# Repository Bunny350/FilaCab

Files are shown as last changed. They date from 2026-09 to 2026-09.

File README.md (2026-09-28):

# FilaCab

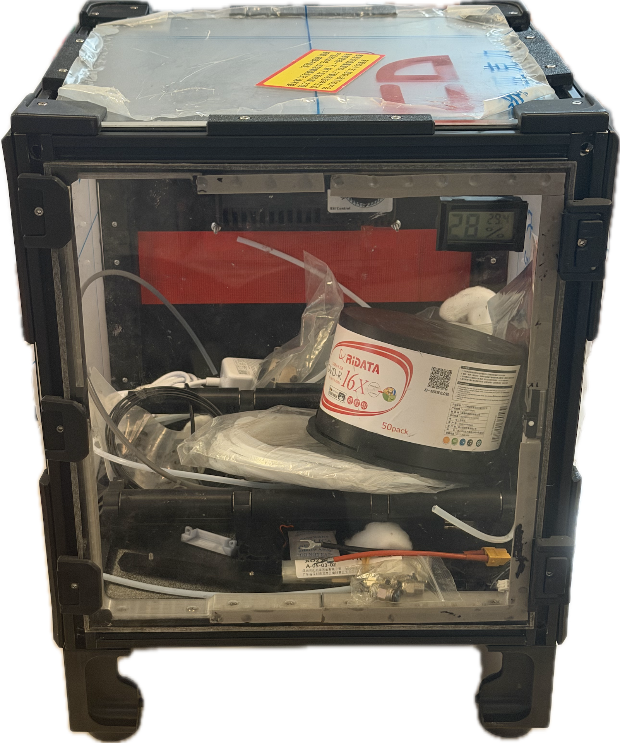
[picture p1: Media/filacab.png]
FilaCab


FilaCab is a 3-spool dry cabinet intended for storing FFF 3D printer filament spools with some Voron design. It contains parts derived from [V2, specifically my 150mm mod / OitswilliamV2](https://github.com/Bunny350/OitswilliamV2) and Voron Trident.

## Because there are no raw materials seen in the CAD, this lists (almost) all the raw materials.
* Side and back panel mounting brackets: 4X M3x10mm BHCS + 4X M3 T-wing or T-nuts per part, totaling 48X M3x10mm BHCS and 48X M3 T-wing or T-nuts,
* Top panel mounting brackets: 16X M3x8mm BHCS + 16X M3 T-wing or T-nuts,
* Panel shields (top and bottom): 4X M3x8mm SHCS + 4X M3 T-wing or T-nuts per part, totaling 32X M3x8mm SHCS and 32X M3 T-wing or T-nuts,
* Side shields (except back): 14X M3x6mm BHCS + 14X M3 T-wing or T-nuts and 2X M5x10mm BHCS + 2X M5 T-wing or T-nuts per side, totaling 38X M3x6mm, 38X M3 T-wing or T-nuts, 4X M5x10mm BHCS and 4X M5 T-wing or T-nuts,
* Back shield: 16X M3x6mm BHCS + 16X M3 T-wing or T-nuts,
* Front shield + frame-side door seal: 16X M3x8mm BHCS and 16X M3 T-wing or T-nuts,
* Dryer unit mounting: at least 4X M3x20mm BHCS + 4X M3 self-locking hex nuts,
* Filament holder with rollers (in case if it ever has MMU implemented): 12X F695 (ZZ or 2RS) bearings (inserted to the holders), 4X M5x10mm BHCS for mounting the roller to the bearings, 8X M3x12mm SHCS and 8X M3 T-wing or T-nuts
* Door seal magnets: Left 20X 6x3mm neodymium N35 magnets per side, Right 32X 6x3mm neodymium N35 magnets (the higher, the better), per side, totaling 104X of them.
  * Magnet placement guide: 
* File guides - CAD component
  * [ref] - reference material used for creating - do not print.
* File guides - printable parts
  * SIdes (after the part name), t - top, b - bottom, l - left, r - right. Some parts may use two-side combination i.e. tl\_br, meaning top-left, bottom-right.

## Development
The development began on 2023 with the first method being just heat, but the efficiency was too low with constant 200W, the second method replaces it with the Peltier, but it is also inefficient due to lacking of airflow. This is then changed to desiccant-based, which can drop to around 30%, or even around 20%.

This project has been released to the public because there are filament manufacturers began building filament dry cabinets, aside non-filament manufacturers have already been building these eons ago.

By using FilaCab, you agree to GNU GPLv3 which is available in the *LICENSE* document. FilaCab uses some parts from Voron 2, including the door hinge, some parts from Voron Trident, such as the feet, and [Snap Latch by richardjm](https://github.com/VoronDesign/VoronUsers/tree/main/printer_mods/richardjm/snap-latch-2020).

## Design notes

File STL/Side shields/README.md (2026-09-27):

# Side shields
This folder contains side shieldings for FilaCab, with the goal of reducing air leaks (as defined by unexpected humidity rise from outside factor).
## Left and right sides
They both use specific sets of `side_bracket_bl_X2.stl` and `side_bracket_br_X2.stl` while using a set of `side_bracket_tl_br_X4.stl` and `side_bracket_bl_tr_X4.stl`. They are mounted per side.
## Back side
This side uses two sets of `side_bracket_tl_br_X4.stl` and `side_bracket_bl_tr_X4.stl`, mounted on the back corners.

## File guide
Please refer to the root Readme file for the after-part name file guide.

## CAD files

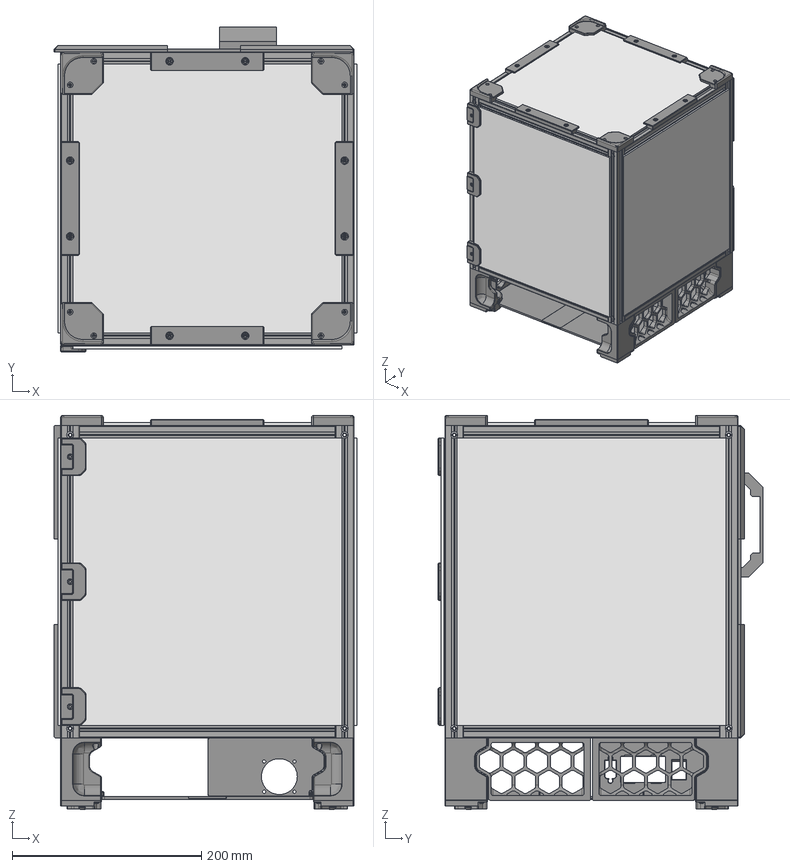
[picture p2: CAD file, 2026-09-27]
CAD/filacab.step
320.0 x 343.0 x 416.3 mm
M5x16 BHCS x 20
HFSB5-2020-430-LCP-RCP x 4
M3x6 BHCS (2)
M3x6 BHCS (19)
M3x6 BHCS (18)
M5x10 BHCS (32)
M3x8 SHCS (69)
M5x16 BHCS (5)
M5 Hex Nut (10)
M3x8 SHCS (70)
M5x10 BHCS (48)
M3x6 BHCS (22)
M3x6 BHCS (21)
M3x6 BHCS (20)
M5x16 BHCS (39)
M5 Hex Nut (12)
M3x8 SHCS (71)
M5x10 BHCS (5)
M3x6 BHCS (25)
M3x6 BHCS (24)
M3x6 BHCS (23)
M5x16 BHCS (40)
M5 Hex Nut (13)
M3x8 SHCS (72)
M5x10 BHCS (4)
M3x6 BHCS (28)
M3x6 BHCS (27)
M3x6 BHCS (26)
M5x16 BHCS (41)
M5 Hex Nut (14)
filament-spol-1kg
Panels
skirt assem
tooled roller
toolless roller
shaft
tooled roller(Mirror)
toolless roller(Mirror)
shaft(Mirror)
door_hinge_x6 (2)
M3x8 SHCS (122)
VHB (16)
M3 Hammerhead T-Nut (61)
door_hinge_x6
M3x8 SHCS (120)
VHB (19)
M3 Hammerhead T-Nut (59)
door_hinge_x6 (1)
M3x8 SHCS (121)
VHB (18)
M3 Hammerhead T-Nut (60)
reverse-stack
splitted bottom
panel mount
maglock
Bottom Panel
side extrusion cover
side extrusion cover(Mirror)
back extrusion cover
top corner extrusion cover

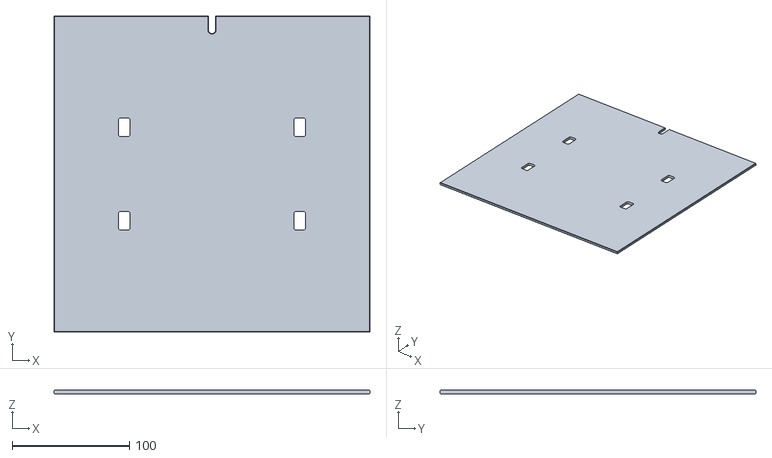
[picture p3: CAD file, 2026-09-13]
STL/bottom_panel_3mm.stl
270.0 x 270.0 x 3.00

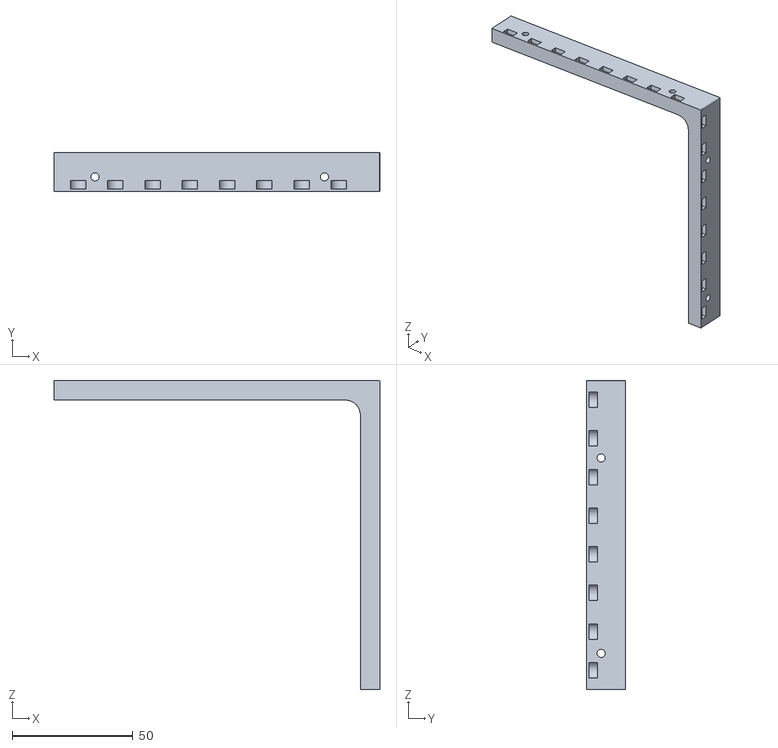
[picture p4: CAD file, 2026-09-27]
STL/Door seal - frame-side/seal_door_maglock_bl_tr_X2.stl
135.0 x 16.0 x 128.0

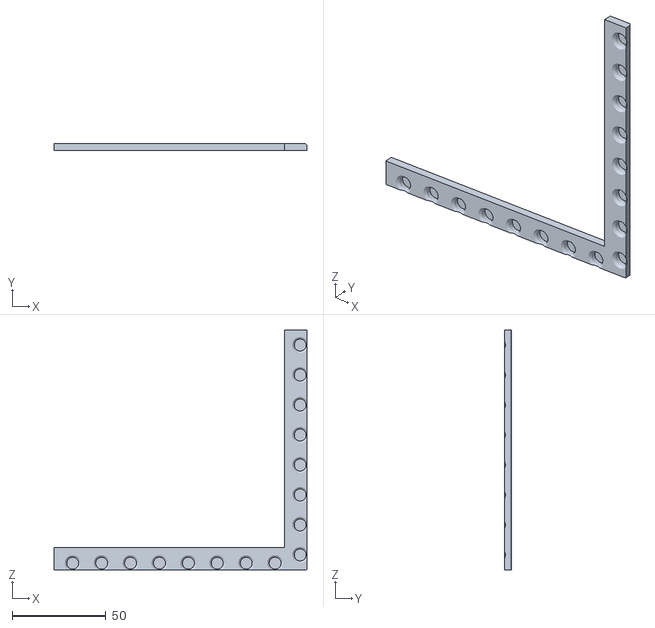
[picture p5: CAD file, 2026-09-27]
STL/Door seal - panel-side/panel_mag_l_tl_br_X2.stl
135.0 x 4.00 x 128.0

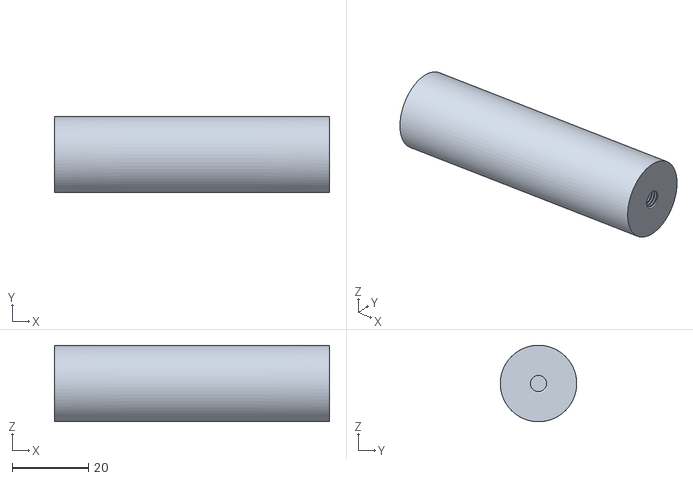
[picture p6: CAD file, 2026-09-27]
STL/Filament rolling/roller_m5_fasten_X4.stl
72.0 x 20.0 x 20.0

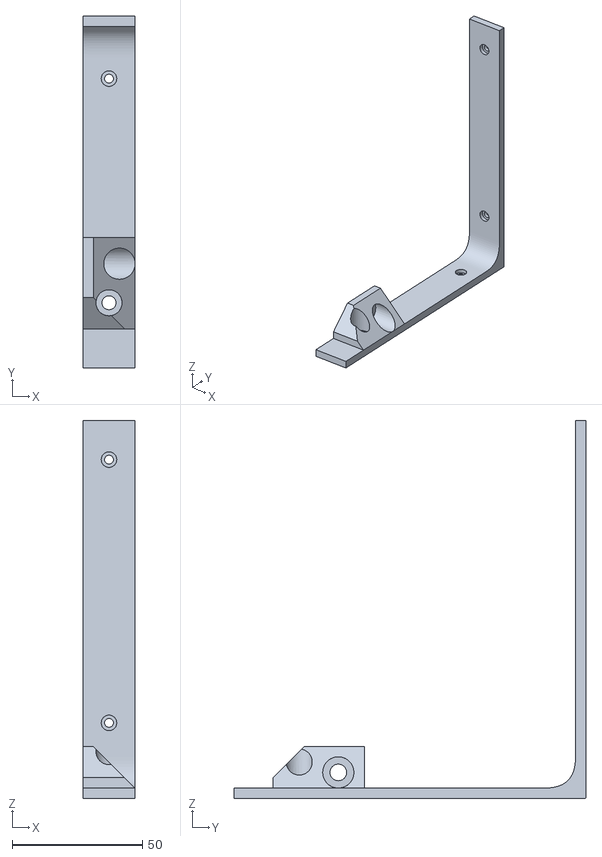
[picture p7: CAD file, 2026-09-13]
STL/Side shields/side_bracket_ext_br_X2.stl
20.0 x 135.0 x 145.0

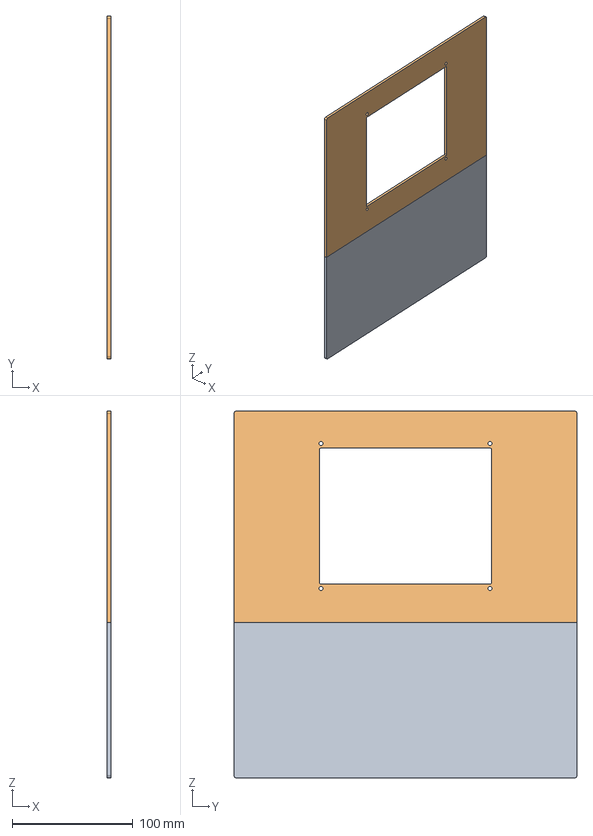
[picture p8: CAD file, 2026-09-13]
CAD/dehumidifier panel for last resort fila cab.step
3.00 x 284.0 x 304.0 mm

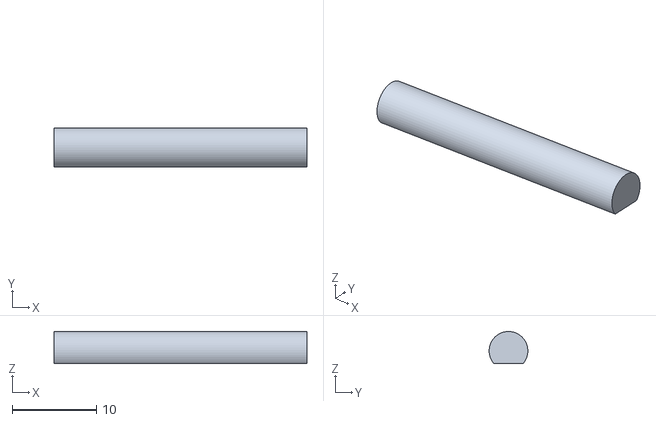
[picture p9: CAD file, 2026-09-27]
STL/Filament rolling/roller_toolless_shaft_X8.stl
30.0 x 4.59 x 3.80

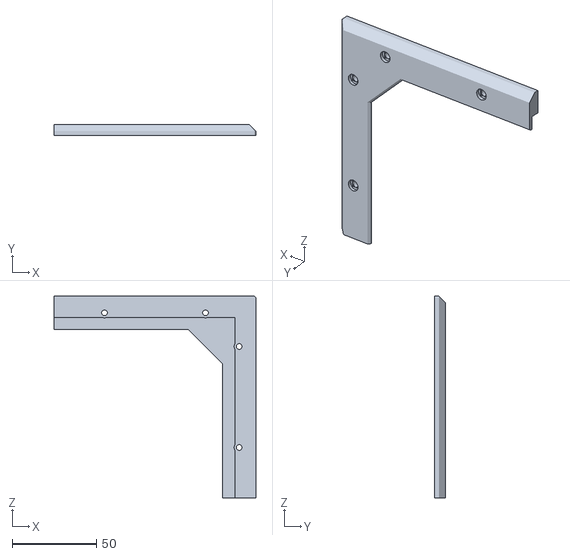
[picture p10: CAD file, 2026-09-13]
STL/panel_corner_mount_X12.stl
120.0 x 6.60 x 120.0

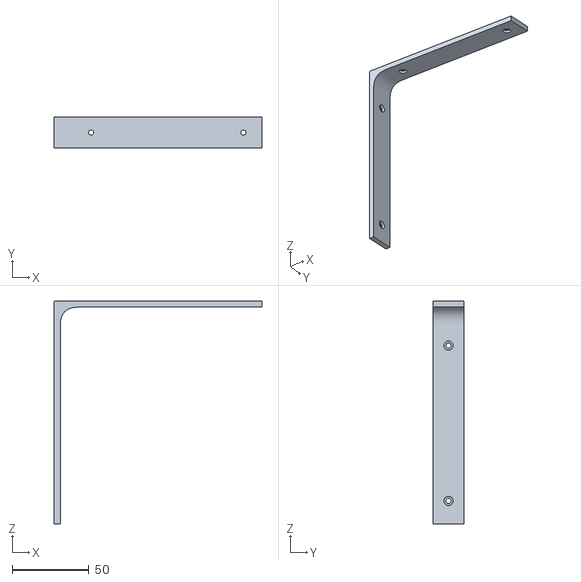
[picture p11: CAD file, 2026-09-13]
STL/Side shields/side_bracket_bl_tr_X4.stl
135.0 x 20.0 x 145.0

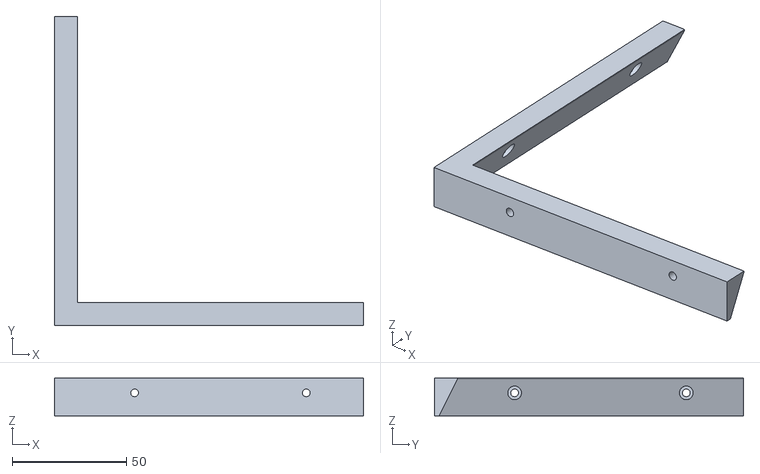
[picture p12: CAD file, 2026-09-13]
STL/bottom_panel_corner_X4.stl
135.0 x 135.0 x 16.4

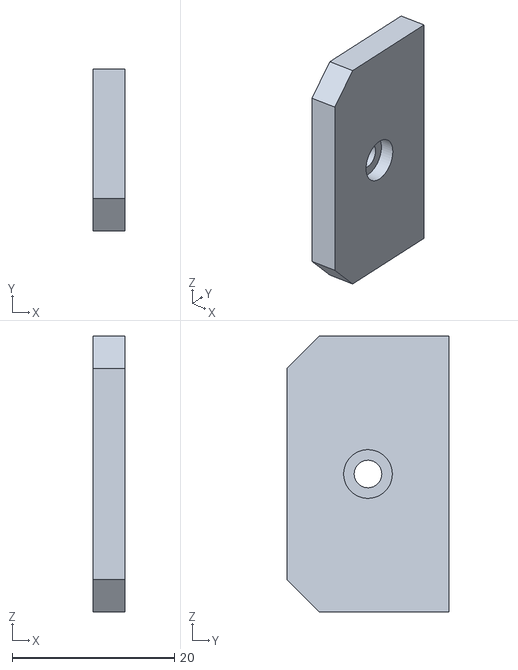
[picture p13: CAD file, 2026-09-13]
STL/Door seal - frame-side/panel_cover_l.stl
4.00 x 20.0 x 34.0

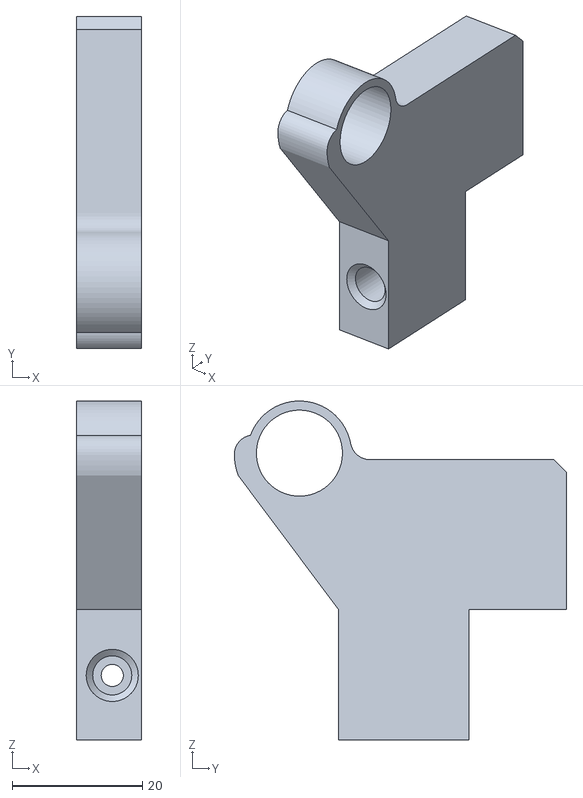
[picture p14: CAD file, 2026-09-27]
STL/Filament rolling/spool_holder_front_X4.stl
10.0 x 51.0 x 52.0

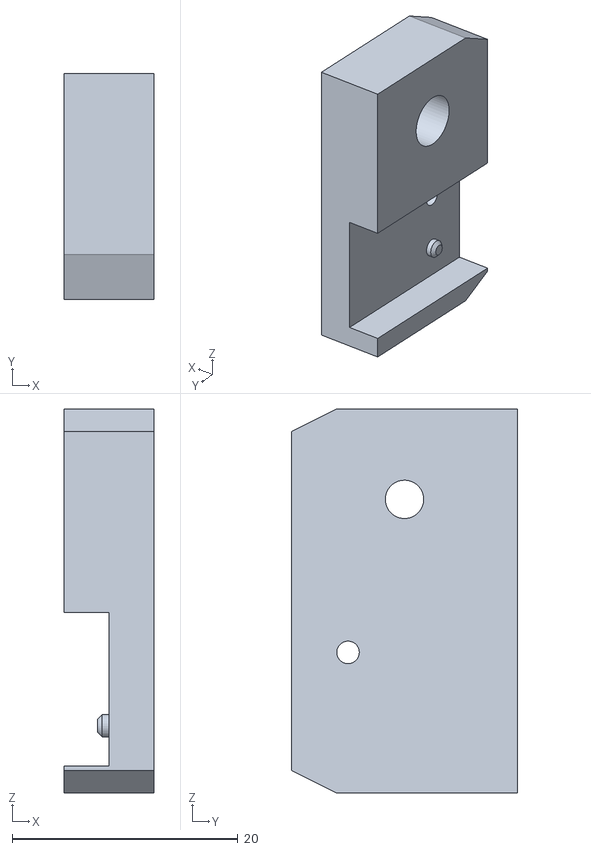
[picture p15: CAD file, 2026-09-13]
STL/Door seal - frame-side/switch_pod.stl
8.00 x 20.0 x 34.0

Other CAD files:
STL/Door seal - frame-side/seal_door_maglock_tl_br_X2.stl
STL/Door seal - panel-side/panel_mag_l_bl_tr_X2.stl
STL/Side shields/side_bracket_ext_bl_X2.stl
STL/Filament rolling/roller-toolless_X2.stl
CAD/dehumidifier panel for last resort fila cab.f3d
CAD/filacab.f3d
STL/Side shields/side_bracket_tl_br_X4.stl
STL/top_panel_extrusion_corner.stl

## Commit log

2026-09-13 Public release
    We have been baking FilaCab and stayed it internal / interview-exclusive until there are filament manufacturers building today's dry cabinet with filaments as sole content.
    [bottom_panel_3mm.stl, bottom_panel_corner_4X.stl, dehumidifier panel for last resort fila cab.f3d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]
2026-09-13 Adjustments
    This change adds the STEP file version of the compatibility panel that can be FFF-printed and explains more on derivatives.
    [dehumidifier panel for last resort fila cab.step]
2026-09-27 New changes
    This update changes the way FilaCab's door shut, in an attempt to reduce air leaks inside the chamber.
    Aside this, it updates the CAD document to contain positions and minimum quantity in bodies, and change the quantity count formatting.
    This also updates the Readme document to have the updated magnet array count and contain the file guide.
    [bottom_panel_corner_X4.stl, filacab.f3d, filacab.step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]
2026-09-27 Rename component names and add side shield Readme file
    This change adjusts required quantity and the installable sides of the side brackets.
    [filacab.f3d, filacab.step, side_bracket_bl_tr_X4.stl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]
2026-09-28 Update README.md
    This only updates the quantity of the fasteners for the front shield, also known as frame-side door seal.
